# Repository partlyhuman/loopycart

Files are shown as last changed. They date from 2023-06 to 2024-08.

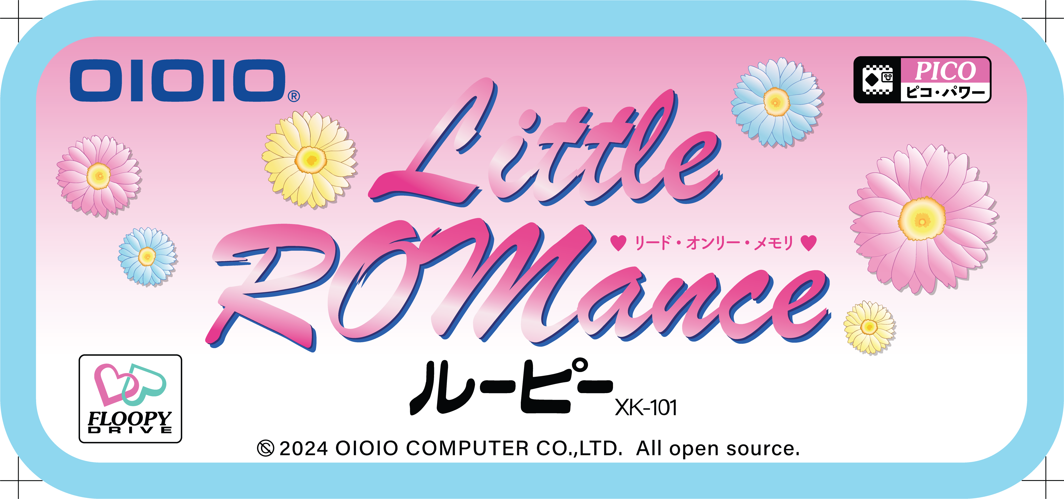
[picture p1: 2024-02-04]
labels/ROMance-1200dpi.png

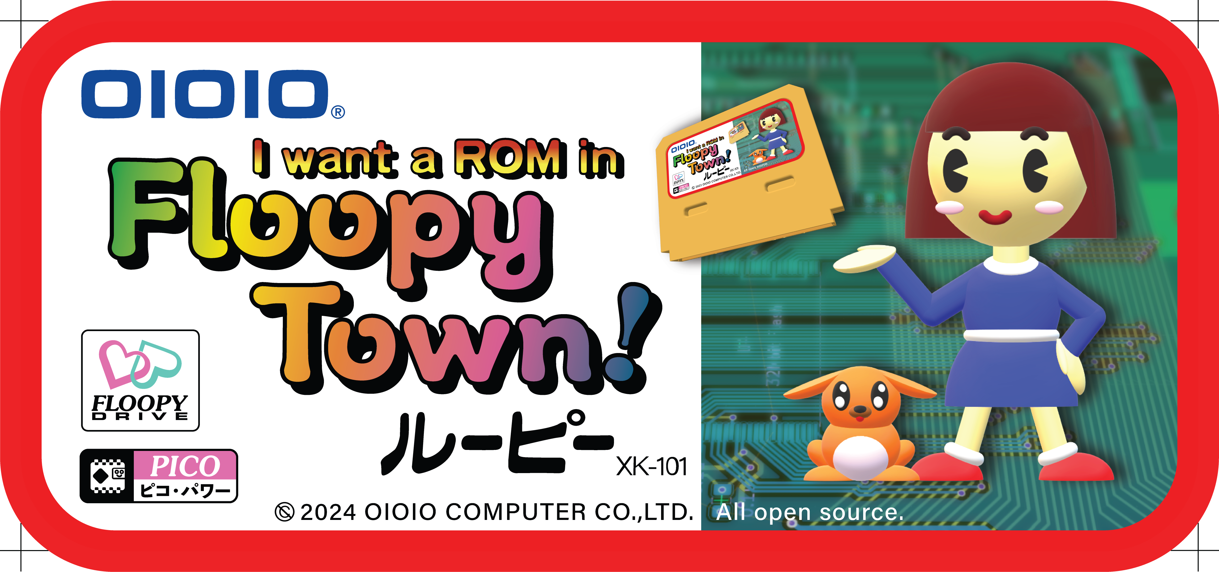
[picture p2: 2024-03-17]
labels/FloopyTown-1200dpi.png

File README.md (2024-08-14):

# the Floopy Drive 💕

This is a flashcart/devcart for the Casio Loopy. 

[☕️ Pre-built carts shipping worldwide on loopy.land/shop](https://loopy.land/shop)

[📖 User's Guide](https://github.com/partlyhuman/loopycart/wiki)

[YouTube<br>📺 Introductory Video](http://www.youtube.com/watch?v=_Q8cJwyDRfA)

To help find your way around:

* [pcb/flash-32mbit/](pcb/flash-32mbit/) The star of the show, the Floopy Drive PCB
* [flash-programmer/](flash-programmer/) Firmware that runs on the Floopy Drive, plus the PC interface for flashing it
* [cart-shell/](cart-shell/) 3D printable case for the Floopy Drive
* [labels/](labels/) Printable labels you can affix to a finished Floopy Drive
* [pcb/](pcb/) Other boards built along the way include a reverse-engineered cart that started it all
* [scans/](scans/) Scans of de-populated OEM Loopy games used as reference
* [data/](data/) Archive of relevant part datasheets for quick reference

Related repositories:

* [OSCR](https://github.com/sanni/cartreader) — I contributed a Casio Loopy adapter and code to the Open Source Cartridge Dumper, as well as a [makeshift adapter](https://github.com/sanni/cartreader/discussions/354#discussioncomment-10103848) that doesn't require an original cart connector
* [Loopy-Tools](https://github.com/kasamikona/Loopy-Tools) — a treasure trove of documentation and tooling around the Loopy by @kasamikona
* [Loopy-Schematics](https://github.com/kasamikona/Loopy-Schematics) - Schematics for various parts of, and accessories for, the Casio Loopy by @kasamikona
* [LoopyMSE](https://github.com/PSI-Rockin/LoopyMSE) — an open-source cross-platform Loopy emulator by @PSI-Rockin

### Contributors! 💕

None of this would be possible without the contributions of [@kasamikona](https://github.com/kasamikona) and [@kvanderlaag](https://github.com/kvanderlaag), with many, many additional thanks to the members of the [Unloved Budget Computer Hole](https://discord.gg/DH8cArK2) Discord server.

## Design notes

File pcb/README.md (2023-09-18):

# Loopy flashcarts/devcarts

* [flash-32mbit](flash-32mbit/) — the Floopy Drive, with 32Mbit tri-voltage flash, and 256kbit SRAM
* [cart-connector](cart-connector/) — cart connector, footprint and symbol, for use in dumpers etc.
* [reverse-singlerom](reverse-singlerom/) — this is the AN1M cart design that we first reverse engineered
* [reverse-wanwan](reverse-wanwan/) — expanding upon that to try to document wanwan, schematic only so far

Some earlier revisions and experiments are in git history.

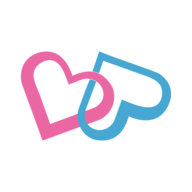
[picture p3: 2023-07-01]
flash-programmer/www/src/assets/android-chrome-192x192.png

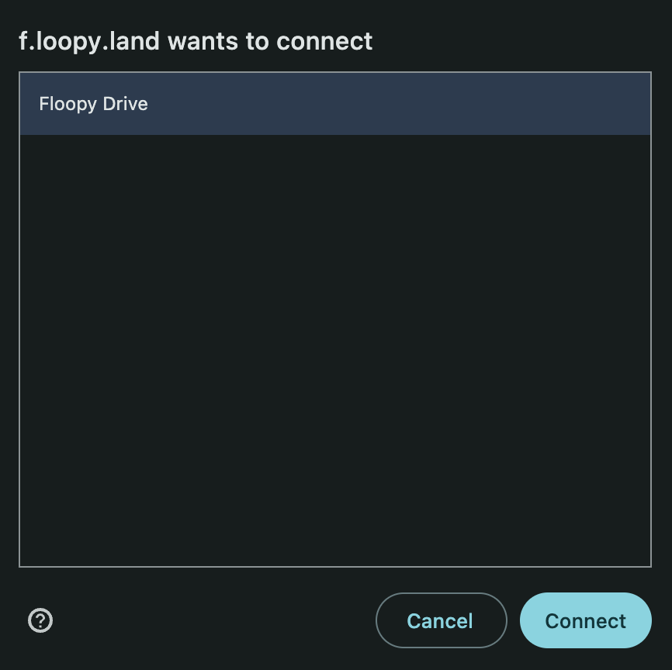
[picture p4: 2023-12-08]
docs/wants-to-connect.png

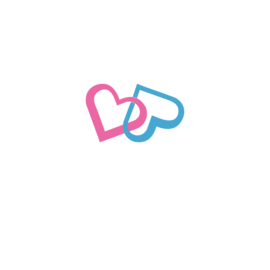
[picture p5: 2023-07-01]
flash-programmer/www/src/assets/mstile-150x150.png

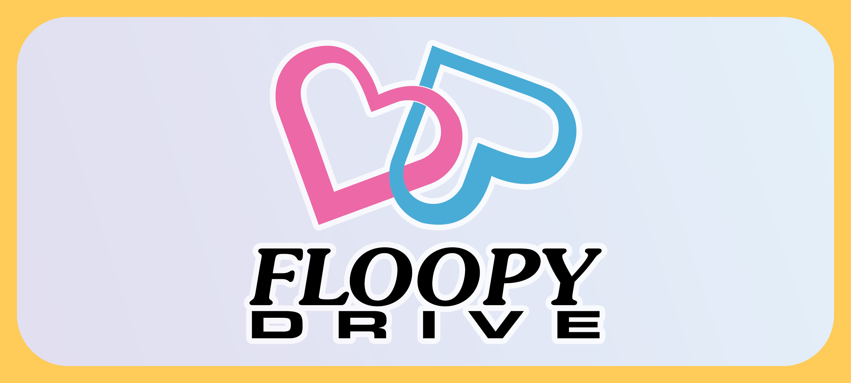
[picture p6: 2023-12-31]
labels/plain.png

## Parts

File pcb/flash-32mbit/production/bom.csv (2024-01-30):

Designator | Footprint | Quantity | Value | LCSC Part #
BT1 | Keystone-3034TR-MFG | 1 | CR2032
C1 | 0805 | 1 | 1u
C2, C4, C5, C6, C7 | 0805 | 5 | 0.1u
D1 | SOT-23 | 1 | BAT54C
D2 | SOT-23-3 | 1 | PMEG4005CT,215
D3 | SOT-23 | 1 | BSS138
J1 | LOOPY_Cart_Edge | 1 | ~
R1 | 0805 | 1 | 1K2
R10 | 0805 | 1 | 2K2
R11, R14, R3, R4, R5, R8 | 0805 | 6 | 100K
R12 | 0805 | 1 | 10K
R13, R2, R6, R9 | 0805 | 4 | 1K
U1 | TSOP-I-56_18.4x14mm_P0.5mm-HandSolder | 1 | LH28F320SKTD-L70
U2 | SOIC127P1410X300-32N | 1 | AS6C1008-55SIN
U3 | SOT-23-5 | 1 | SN74LVC1G04
U4 | RP2040-Tiny | 1 | RP2040-Tiny
U5, U6, U7 | SSOP-28_5.3x10.2mm_P0.65mm | 3 | MCP23S17T-E/SS

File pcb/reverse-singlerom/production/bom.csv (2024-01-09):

Designator | Footprint | Quantity | Value | LCSC Part #
IC11 | LOOPY-SOIC-44 | 1 | ~
J11, J12 | PinHeader_1x21_P2.54mm_Vertical | 2 | Conn_01x21_Pin

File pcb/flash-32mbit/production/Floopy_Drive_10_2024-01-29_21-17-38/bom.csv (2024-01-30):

Designator | Footprint | Quantity | Value | LCSC Part #
BT1 | Keystone-3034TR-MFG | 1 | CR2032
C1 | 0805 | 1 | 1u
C2, C4, C5, C6, C7 | 0805 | 5 | 0.1u
D1 | SOT-23 | 1 | BAT54C
D2 | SOT-23-3 | 1 | PMEG2005CT_215
D3 | SOT-23 | 1 | BSS138
J1 | LOOPY_Cart_Edge | 1 | ~
R1 | 0805 | 1 | 1K2
R10 | 0805 | 1 | 2K2
R11, R3, R4, R8 | 0805 | 4 | 100K
R12 | 0805 | 1 | 10K
R13, R2, R6, R9 | 0805 | 4 | 1K
R14, R5 | 0805 | 2 | 100K | DNP
U1 | TSOP-I-56_18.4x14mm_P0.5mm-HandSolder | 1 | LH28F320SKTD-L70
U2 | SOIC127P1410X300-32N | 1 | AS6C1008-55SIN
U3 | SOT-23-5 | 1 | SN74LVC1G04
U4 | RP2040-Tiny | 1 | RP2040-Tiny
U5, U6, U7 | SSOP-28_5.3x10.2mm_P0.65mm | 3 | MCP23S17T-E/SS

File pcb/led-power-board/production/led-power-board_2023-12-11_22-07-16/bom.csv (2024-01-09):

Designator | Footprint | Quantity | Value | LCSC Part #
D1 | LED_D5.0mm | 1 | LED
J1 | PinHeader_1x02_P2.54mm_Vertical | 1 | Conn_01x02_Pin
R1 | R_Axial_DIN0207_L6.3mm_D2.5mm_P10.16mm_Horizontal | 1 | 1K

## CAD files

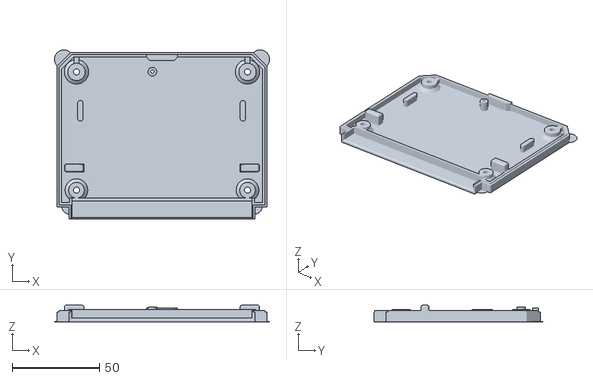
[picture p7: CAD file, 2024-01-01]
cart-shell/FloopyDrive-Rear-MouseEars.stl
123.4 x 97.1 x 9.60

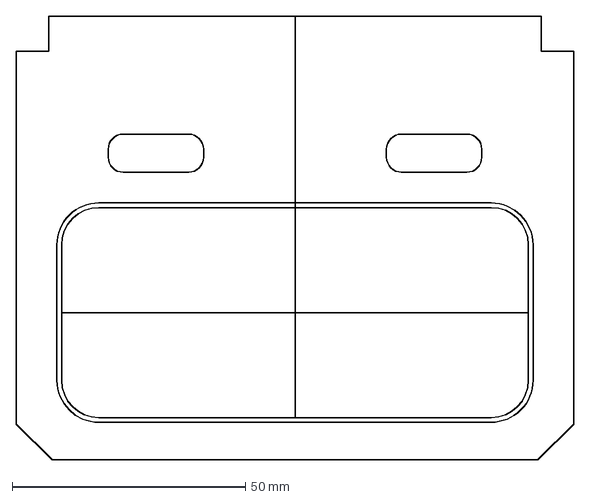
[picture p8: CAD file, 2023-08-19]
labels/floopycart-label.dxf
119.4 x 95.1 mm

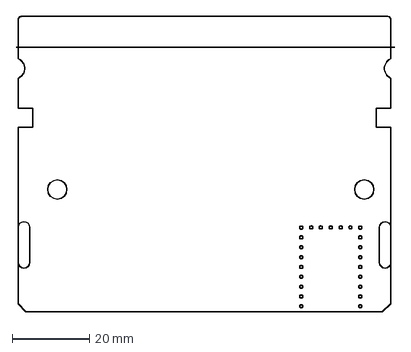
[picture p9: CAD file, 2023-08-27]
pcb/flash-32mbit/Reference/PCB Keepouts Front.dxf
97.8 x 76.3 mm

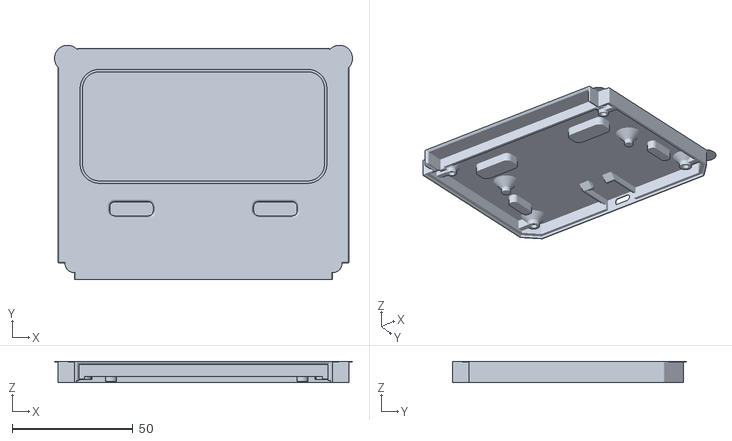
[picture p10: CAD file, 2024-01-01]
cart-shell/FloopyDrive-Front-MouseEars.stl
123.4 x 97.1 x 8.85

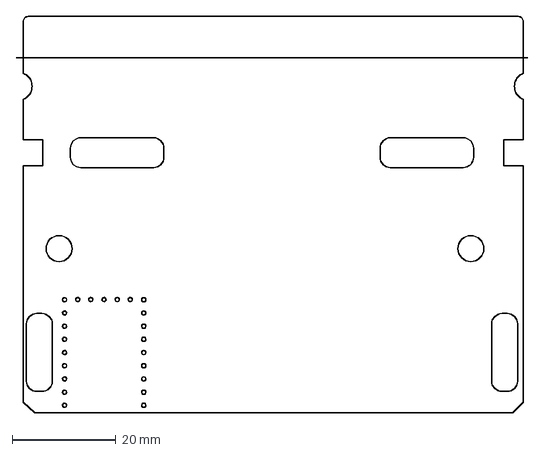
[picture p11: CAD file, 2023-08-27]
pcb/flash-32mbit/Reference/PCB Keepouts Rear.dxf
98.4 x 76.3 mm

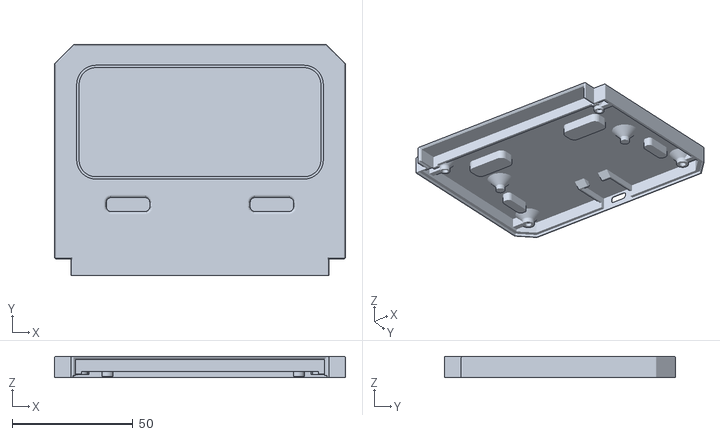
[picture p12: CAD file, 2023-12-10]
cart-shell/FloopyDrive-Front.stl
120.6 x 95.7 x 8.85

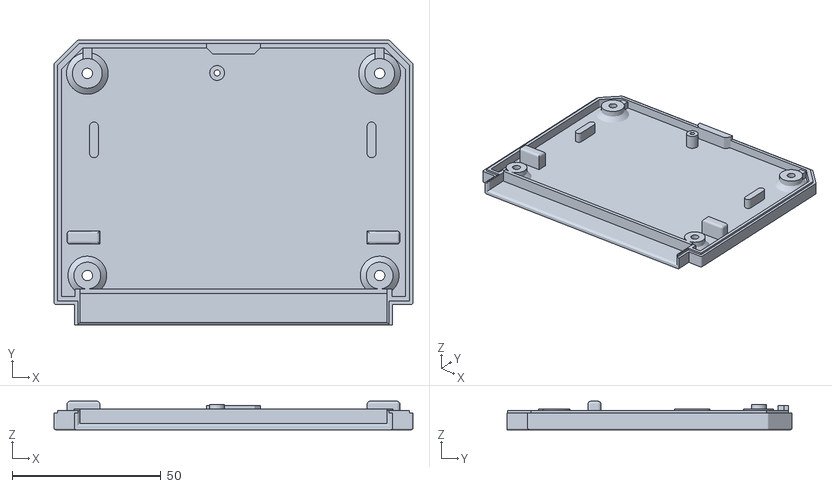
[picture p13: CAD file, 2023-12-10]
cart-shell/FloopyDrive-Rear.stl
120.6 x 95.7 x 9.60

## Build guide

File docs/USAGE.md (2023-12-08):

> NOTE migrated to https://github.com/partlyhuman/loopycart/wiki

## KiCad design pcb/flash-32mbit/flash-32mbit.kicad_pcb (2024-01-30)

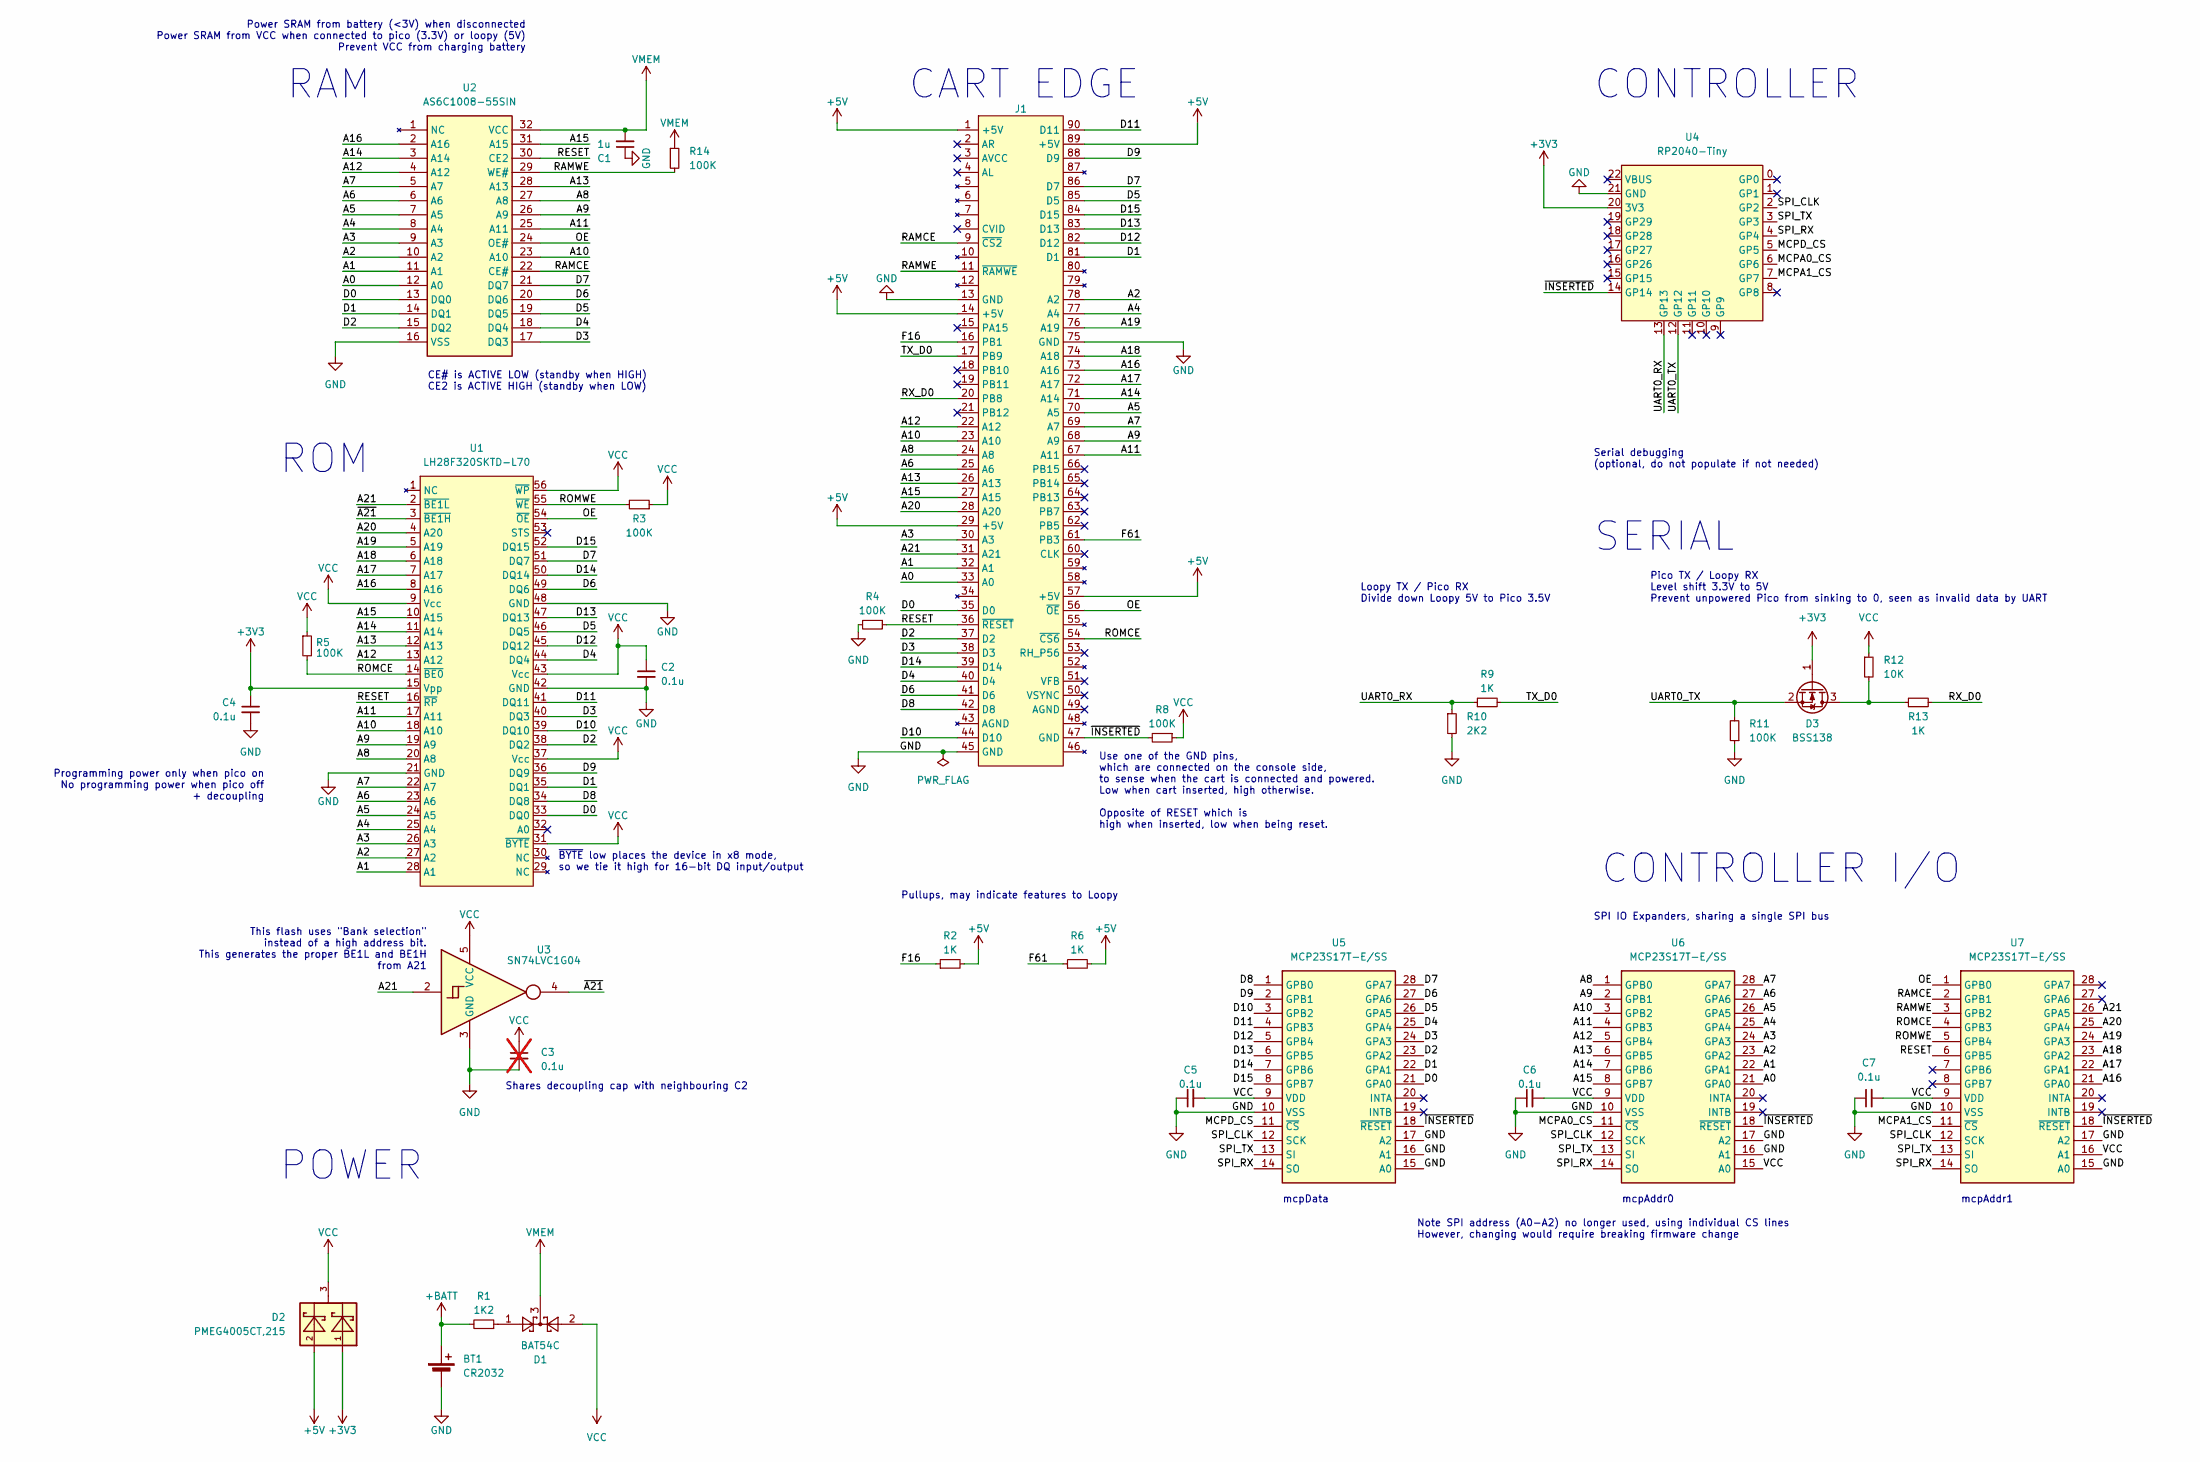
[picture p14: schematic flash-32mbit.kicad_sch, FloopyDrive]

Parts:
BT1: CR2032; Keystone-3034TR-MFG
C1: 1u; C_0805_2012Metric_Pad1.18x1.45mm_HandSolder
C2, C4, C5, C6, C7: 0.1u; C_0805_2012Metric_Pad1.18x1.45mm_HandSolder
C3: 0.1u; C_0805_2012Metric_Pad1.18x1.45mm_HandSolder; not fitted
D1: BAT54C; SOT-23
D2: PMEG4005CT,215; SOT-23-3
D3: BSS138; SOT-23
J1: LOOPY_Cart_Edge
R1: 1K2; R_0805_2012Metric_Pad1.20x1.40mm_HandSolder
R2, R6, R9, R13: 1K; R_0805_2012Metric_Pad1.20x1.40mm_HandSolder
R3, R4, R5, R8, R11, R14: 100K; R_0805_2012Metric_Pad1.20x1.40mm_HandSolder
R10: 2K2; R_0805_2012Metric_Pad1.20x1.40mm_HandSolder
R12: 10K; R_0805_2012Metric_Pad1.20x1.40mm_HandSolder
U1: LH28F320SKTD-L70; TSOP-I-56_18.4x14mm_P0.5mm-HandSolder
U2: AS6C1008-55SIN; SOIC127P1410X300-32N; Manufacturer_Part_Number AS6C1008-55SIN; Mouser Part Number 913-AS6C1008-55SIN
U3: SN74LVC1G04; SOT-23-5
U4: RP2040-Tiny
U5, U6, U7: MCP23S17T-E/SS; SSOP-28_5.3x10.2mm_P0.65mm; Manufacturer_Part_Number MCP23S17T-E/SO; Mouser Part Number 579-MCP23S17T-E/SO

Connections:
+3V3: C4.1, D2.1, D3.1 (G), U1.15 (Vpp), U4.20 (3V3)
+5V: D2.2, J1.1 (+5V), J1.14 (+5V), J1.29 (+5V), J1.57 (+5V), J1.89 (+5V), R2.2, R6.2
+BATT: BT1.1 (+), R1.2
/A0: J1.33 (A0), U2.12 (A0), U6.21 (GPA0)
/A1: J1.32 (A1), U1.28 (A1), U2.11 (A1), U6.22 (GPA1)
/A2: J1.78 (A2), U1.27 (A2), U2.10 (A2), U6.23 (GPA2)
/A3: J1.30 (A3), U1.26 (A3), U2.9 (A3), U6.24 (GPA3)
/A4: J1.77 (A4), U1.25 (A4), U2.8 (A4), U6.25 (GPA4)
/A5: J1.70 (A5), U1.24 (A5), U2.7 (A5), U6.26 (GPA5)
/A6: J1.25 (A6), U1.23 (A6), U2.6 (A6), U6.27 (GPA6)
/A7: J1.69 (A7), U1.22 (A7), U2.5 (A7), U6.28 (GPA7)
/A8: J1.24 (A8), U1.20 (A8), U2.27 (A8), U6.1 (GPB0)
/A9: J1.68 (A9), U1.19 (A9), U2.26 (A9), U6.2 (GPB1)
/A10: J1.23 (A10), U1.18 (A10), U2.23 (A10), U6.3 (GPB2)
/A11: J1.67 (A11), U1.17 (A11), U2.25 (A11), U6.4 (GPB3)
/A12: J1.22 (A12), U1.13 (A12), U2.4 (A12), U6.5 (GPB4)
/A13: J1.26 (A13), U1.12 (A13), U2.28 (A13), U6.6 (GPB5)
/A14: J1.71 (A14), U1.11 (A14), U2.3 (A14), U6.7 (GPB6)
/A15: J1.27 (A15), U1.10 (A15), U2.31 (A15), U6.8 (GPB7)
/A16: J1.73 (A16), U1.8 (A16), U2.2 (A16), U7.21 (GPA0)
/A17: J1.72 (A17), U1.7 (A17), U7.22 (GPA1)
/A18: J1.74 (A18), U1.6 (A18), U7.23 (GPA2)
/A19: J1.76 (A19), U1.5 (A19), U7.24 (GPA3)
/A20: J1.28 (A20), U1.4 (A20), U7.25 (GPA4)
/A21: J1.31 (A21), U1.2 (~BE1L), U3.2, U7.26 (GPA5)
/D0: J1.35 (D0), U1.33 (DQ0), U2.13 (DQ0), U5.21 (GPA0)
/D1: J1.81 (D1), U1.35 (DQ1), U2.14 (DQ1), U5.22 (GPA1)
/D2: J1.37 (D2), U1.38 (DQ2), U2.15 (DQ2), U5.23 (GPA2)
/D3: J1.38 (D3), U1.40 (DQ3), U2.17 (DQ3), U5.24 (GPA3)
/D4: J1.40 (D4), U1.44 (DQ4), U2.18 (DQ4), U5.25 (GPA4)
/D5: J1.85 (D5), U1.46 (DQ5), U2.19 (DQ5), U5.26 (GPA5)
/D6: J1.41 (D6), U1.49 (DQ6), U2.20 (DQ6), U5.27 (GPA6)
/D7: J1.86 (D7), U1.51 (DQ7), U2.21 (DQ7), U5.28 (GPA7)
/D8: J1.42 (D8), U1.34 (DQ8), U5.1 (GPB0)
/D9: J1.88 (D9), U1.36 (DQ9), U5.2 (GPB1)
/D10: J1.44 (D10), U1.39 (DQ10), U5.3 (GPB2)
/D11: J1.90 (D11), U1.41 (DQ11), U5.4 (GPB3)
/D12: J1.82 (D12), U1.45 (DQ12), U5.5 (GPB4)
/D13: J1.83 (D13), U1.47 (DQ13), U5.6 (GPB5)
/D14: J1.39 (D14), U1.50 (DQ14), U5.7 (GPB6)
/D15: J1.84 (D15), U1.52 (DQ15), U5.8 (GPB7)
/F16: J1.16 (PB1), R2.1
/F61: J1.61 (PB3), R6.1
/MCPA0_CS: U4.6 (GP6), U6.11 (~CS)
/MCPA1_CS: U4.7 (GP7), U7.11 (~CS)
/MCPD_CS: U4.5 (GP5), U5.11 (~CS)
/OE: J1.56 (~OE), U1.54 (~OE), U2.24 (OE#), U7.1 (GPB0)
/RAMCE: J1.9 (~CS2), U2.22 (CE#), U7.2 (GPB1)
/RAMWE: J1.11 (~RAMWE), R14.2, U2.29 (WE#), U7.3 (GPB2)
/RESET: J1.36 (~RESET), R4.1, U1.16 (~RP), U2.30 (CE2), U7.6 (GPB5)
/ROMCE: J1.54 (~CS6), R5.2, U1.14 (~BE0), U7.4 (GPB3)
/ROMWE: R3.2, U1.55 (~WE), U7.5 (GPB4)
/RX_D0: J1.20 (PB8), R13.2
/SPI_CLK: U4.2 (GP2), U5.12 (SCK), U6.12 (SCK), U7.12 (SCK)
/SPI_RX: U4.4 (GP4), U5.14 (SO), U6.14 (SO), U7.14 (SO)
/SPI_TX: U4.3 (GP3), U5.13 (SI), U6.13 (SI), U7.13 (SI)
/TX_D0: J1.17 (PB9), R9.2
/UART0_RX: R9.1, R10.1, U4.13 (GP13)
/UART0_TX: D3.2 (S), R11.2, U4.12 (GP12)
/~A21: U1.3 (~BE1H), U3.4
/~INSERTED: J1.47 (GND), R8.2, U4.14 (GP14), U5.18 (~RESET), U6.18 (~RESET), U7.18 (~RESET)
GND: BT1.2 (-), C1.1, C2.2, C3.2, C4.2, C5.1, C6.1, C7.1, J1.13 (GND), J1.45 (GND), J1.75 (GND), R4.2, R10.2, R11.1, U1.21 (GND), U1.42 (GND), U1.48 (GND), U2.16 (VSS), U3.3 (GND), U4.21 (GND), U5.10 (VSS), U5.15 (A0), U5.16 (A1), U5.17 (A2), U6.10 (VSS), U6.16 (A1), U6.17 (A2), U7.10 (VSS), U7.15 (A0), U7.17 (A2)
unnamed: D1.1, R1.1
unnamed: D3.3 (D), R12.2, R13.1
VCC: C2.1, C3.1, C5.2, C6.2, C7.2, D1.2, D2.3, R3.1, R5.1, R8.1, R12.1, U1.9 (Vcc), U1.31 (~BYTE), U1.37 (Vcc), U1.43 (Vcc), U1.56 (~WP), U3.5 (VCC), U5.9 (VDD), U6.9 (VDD), U6.15 (A0), U7.9 (VDD), U7.16 (A1)
VMEM: C1.2, D1.3, R14.1, U2.32 (VCC)

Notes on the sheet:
Use one of the GND pins, which are connected on the console side, to sense when the cart is connected and powered. Low when cart inserted, high otherwise. Opposite of RESET which is high when inserted, low when being reset.
Power SRAM from battery (<3V) when disconnected Power SRAM from VCC when connected to pico (3.3V) or loopy (5V) Prevent VCC from charging battery
POWER
RAM
Shares decoupling cap with neighbouring C2
ROM
Loopy TX / Pico RX Divide down Loopy 5V to Pico 3.5V
CE# is ACTIVE LOW (standby when HIGH) CE2 is ACTIVE HIGH (standby when LOW)
Note SPI address (A0-A2) no longer used, using individual CS lines However, changing would require breaking firmware change
CART EDGE
mcpAddr0
mcpAddr1
This flash uses "Bank selection" instead of a high address bit. This generates the proper BE1L and BE1H from A21
Programming power only when pico on No programming power when pico off + decoupling
Pullups, may indicate features to Loopy
Serial debugging (optional, do not populate if not needed)
Pico TX / Loopy RX Level shift 3.3V to 5V Prevent unpowered Pico from sinking to 0, seen as invalid data by UART
SERIAL
SPI IO Expanders, sharing a single SPI bus
~{BYTE} low places the device in x8 mode, so we tie it high for 16-bit DQ input/output
CONTROLLER
CONTROLLER I/O
mcpData

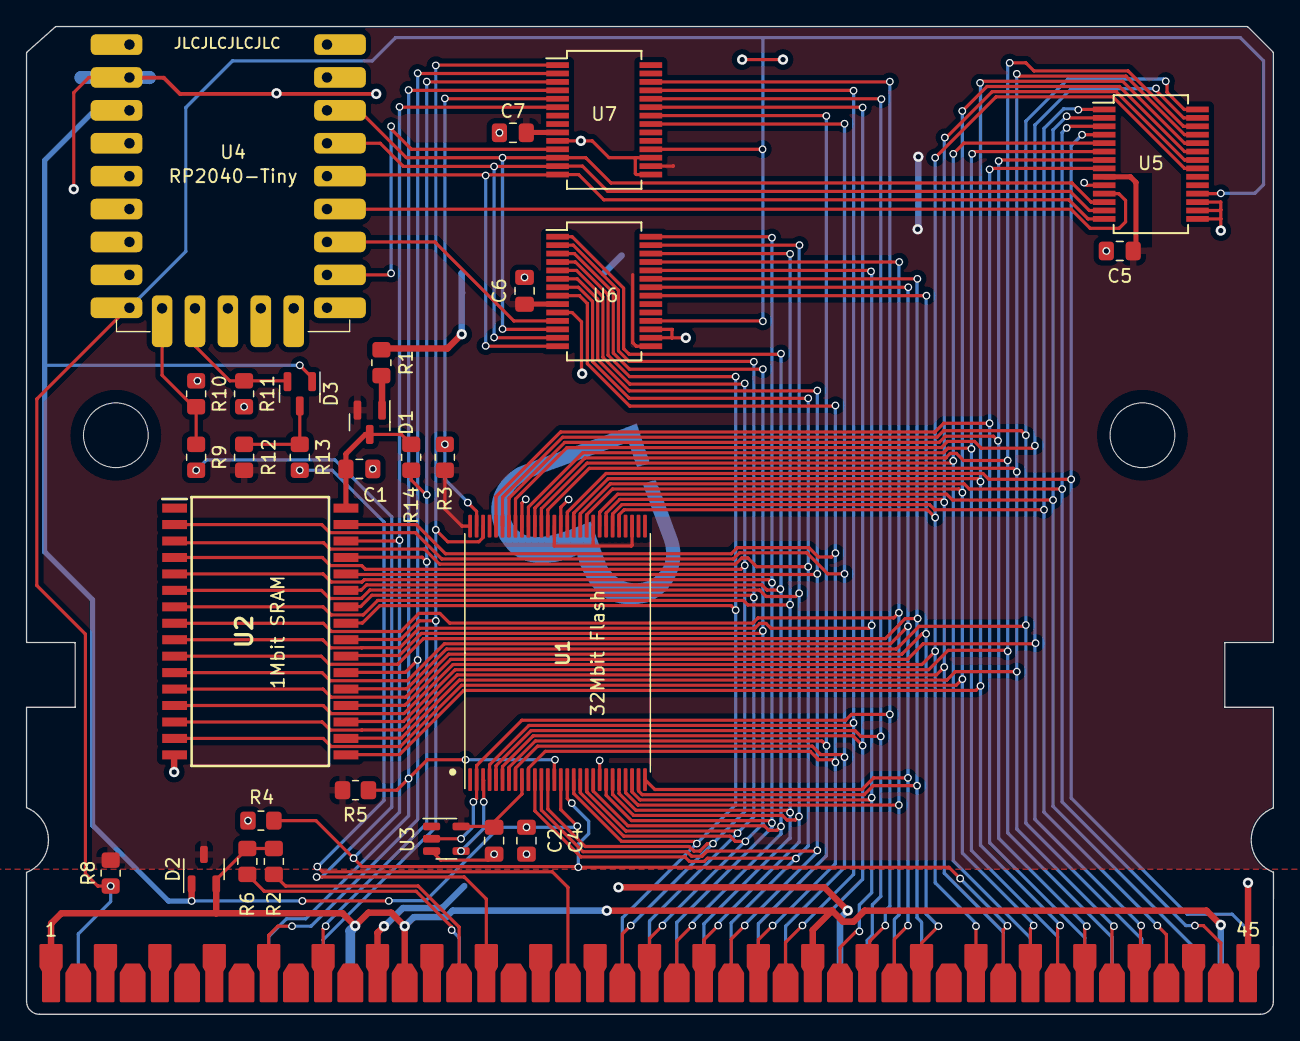
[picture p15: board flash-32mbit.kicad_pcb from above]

Board: 2 copper layers, 96.3 x 76.2 mm, 33 parts (1 on the bottom side), 66 nets.

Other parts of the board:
H1, H2: MountingHole_5mm

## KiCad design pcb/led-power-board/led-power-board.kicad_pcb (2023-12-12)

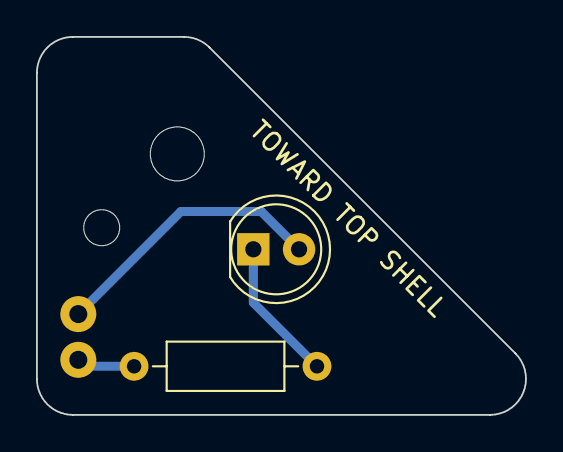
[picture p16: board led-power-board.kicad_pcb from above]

Board: 2 copper layers, 27.2 x 21.0 mm, 6 parts (1 on the bottom side), 3 nets.

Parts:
D1: LED; LED_D5.0mm
J1: Conn_01x02_Pin; PinHeader_1x02_P2.54mm_Vertical
M1: MountingHole_3mm
M2, M3: MountingHole_2mm
R1: 1K; R_Axial_DIN0207_L6.3mm_D2.5mm_P10.16mm_Horizontal

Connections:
unnamed: D1.2 (A), J1.1
unnamed: D1.1 (K), R1.2
unnamed: J1.2, R1.1

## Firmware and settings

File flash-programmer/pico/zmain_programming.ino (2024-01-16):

#define ABORT_AFTER_MS 1000

// Keep Adafruit VID, custom PID for programming
#define VID_PROG 0x239A
#define PID_PROG 0xF100

static int bootErrors = 0;

void onSuccess(bool echoOk = true) {
  if (echoOk) echo_ok();
  busIdle();
  ledColor(0);
}

void loop_programming() {
  static uint8_t buf[USB_BUFSIZE];
  static bool isProgrammingFlash = false;
  static bool isProgrammingSram = false;
  static uint32_t addr = 0;
  static uint32_t totalBytes;
  static uint32_t idleSince = 0;


  if (!usb_web.available()) {
    // DEBUGGING idle detect shows the pico is still looping if other things have halted due to error
    if (idleSince == 0) {
      idleSince = millis();
    } else if (millis() - idleSince > ABORT_AFTER_MS) {
      if (isProgrammingFlash || isProgrammingSram) {
        isProgrammingFlash = false;
        isProgrammingSram = false;
        echo_all("!ERROR Aborted programming after no data\r\n");
      }
    }
    return;
  }
  idleSince = 0;

  size_t bufLen = usb_web.read(buf, USB_BUFSIZE);

  if (isProgrammingFlash) {
    isProgrammingFlash = flashWriteBuffer(buf, bufLen, addr, totalBytes);
    if (!isProgrammingFlash) onSuccess();
    return;
  } else if (isProgrammingSram) {
    isProgrammingSram = sramWriteBuffer(buf, bufLen, addr, totalBytes);
    if (!isProgrammingSram) onSuccess();
    return;
  }

  else if (buf[0] == 'E') {
    // ERASE COMMAND
    if (buf[1] == '\r') {
      ledColor(BLUE);
      flashEraseAll();
      flashCommand(0, CMD_RESET);
      onSuccess();
    } else if (buf[1] == 's' && buf[2] == '\r') {
      ledColor(BLUE);
      sramErase();
      onSuccess();
    } else if (buf[1] == '0' && buf[2] == '\r') {
      // DEPRECATED
      ledColor(BLUE);
      flashEraseBank(0);
      flashCommand(0, CMD_RESET);
      onSuccess();
    } else if (buf[1] == '1' && buf[2] == '\r') {
      // DEPRECATED
      ledColor(BLUE);
      flashEraseBank(1);
      flashCommand(0, CMD_RESET);
      onSuccess();
    } else if (sscanf((char *)buf, "E%ld\r", &totalBytes) && totalBytes > 0 && totalBytes <= FLASH_SIZE) {
      stopwatch = millis();
      sprintf(S, "Erasing %d bytes of flash up to %06xh\r\n", totalBytes, totalBytes);
      echo_all();
      ledColor(BLUE);
      for (addr = 0; addr < totalBytes; addr += FLASH_BLOCK_SIZE) {
        sprintf(S, "%06xh ", addr);
        echo_all();
        if (!flashEraseBlock(addr)) {
          echo_all("\r\n!ERR ABORTING ERASE\r\n");
          return;
        }
      }
      // // NOTE: Erasing by bank isn't faster than erasing by block, so this adds complexity but saves no time
      // addr = 0;
      // while (addr < totalBytes) {
      //   sprintf(S, "%06xh ", addr);
      //   echo_all();
      //   if (addr == 0 && totalBytes >= FLASH_BANK_SIZE) {
      //     flashEraseBank(0);
      //     addr += FLASH_BANK_SIZE;
      //   } else if (addr == FLASH_BANK_SIZE && totalBytes == FLASH_BANK_SIZE * 2) {
      //     flashEraseBank(1);
      //     addr += FLASH_BANK_SIZE;
      //   } else {
      //     if (!flashEraseBlock(addr)) {
      //       echo_all("\r\n!ERR ABORTING ERASE\r\n");
      //       return;
      //     }
      //   }
      // }
      sprintf(S, "\r\nErased %d bytes in %0.2f sec using block erasing\r\n", addr, (millis() - stopwatch) / 1000.0);
      echo_all();
      onSuccess();
    }
  }

  else if (buf[0] == 'I' && buf[1] == '\r') {
    // INSPECT COMMAND
    // flashId();
    echo_all("\r\n---CART-ID---\r\n");
    sprintf(S, "Cart header %s\r\n", flashCartHeaderCheck() ? "OK" : "NOT OK");
    echo_all();
    sprintf(S, "Cart ID %08x\r\n", flashCartHeaderId());
    echo_all();
    echo_all("\r\n---FLASH-lower---\r\n");
    flashInspect(0x000000, 0x000100);
    echo_all("\r\n------\r\n");
    flashInspect(0x100000, 0x100100);
    echo_all("\r\n---FLASH-upper---\r\n");
    flashInspect(0x200000, FLASH_BANK_SIZE + 0x000100);
    echo_all("\r\n------\r\n");
    flashInspect(0x300000, FLASH_BANK_SIZE + 0x100100);
    echo_all("\r\n---SRAM---\r\n");
    sramInspect(0, 0x100);
    echo_all("\r\n---FILESYSTEM---\r\n");
    Dir dir = LittleFS.openDir("/");
    while (dir.next()) {
      echo_all(dir.fileName().c_str());
      echo_all("\r\n");
    }

    // Some info in the info64 struct comes out as zeroes
    // FSInfo64 info;
    // LittleFS.info64(info);
    FSInfo info;
    LittleFS.info(info);
    sprintf(S, "%d/%d bytes used, %0.0f%% full\r\n", info.usedBytes, info.totalBytes, 100.0 * (info.usedBytes + 0.0) / info.totalBytes);
    echo_all();
    onSuccess();
  }

  else if (buf[0] == 'D') {
    // DUMP COMMAND
    if (2 == sscanf((char *)buf, "D%ld/%ld\r", &addr, &totalBytes)) {
      // followed by start address and total # of bytes
      if (addr > 0 && totalBytes > 0 && totalBytes <= FLASH_SIZE) {
        ledColor(BLUE);
        flashDump(addr, addr + totalBytes);
        onSuccess(false);
      } else {
        ledColor(RED);
      }
    } else if (1 == sscanf((char *)buf, "D%ld\r", &totalBytes)) {
      // followed by expected # of bytes
      if (totalBytes > 0 && totalBytes <= FLASH_SIZE) {
        ledColor(BLUE);
        flashDump(0, totalBytes);
        onSuccess(false);
      } else {
        ledColor(RED);
      }
    } else if (buf[1] == 's' && buf[2] == '\r') {
      sramDump();
      onSuccess(false);
    }
  }

  else if (buf[0] == 'P') {
    // PROGRAM COMMAND
    if (1 == sscanf((char *)buf, "P%ld\r", &totalBytes) && totalBytes > 0 && totalBytes <= FLASH_SIZE) {
      // program flash followed by expected # of bytes
      sprintf(S, "Programming %d bytes to flash\r", totalBytes);
      echo_all();
      isProgrammingFlash = true;
      addr = 0;
      stopwatch = millis();
      ledColor(BLUE);
    } else if (1 == sscanf((char *)buf, "Ps%ld\r", &totalBytes) && totalBytes > 0 && totalBytes <= SRAM_SIZE) {
      // program SRAM followed by expected # of bytes
      sprintf(S, "Programming %d bytes to SRAM\r", totalBytes);
      echo_all();
      isProgrammingSram = true;
      addr = 0;
      stopwatch = millis();
      ledColor(BLUE);
    }
  }

  else if (buf[0] == 'S') {
    // SRAM BACKUP & RESTORE FROM FILESYSTEM

    // ID the header
    uint32_t cartId = flashCartHeaderId();

    // we always use <crc32>.sav which is 8 1 3 = 12 chars plus string terminator = 13 bytes
    const size_t SAVE_FILENAME_LEN = 13;
    char filename[SAVE_FILENAME_LEN];
    sprintf(filename, "%08x.sav", cartId);

    if (buf[1] == 'r' && buf[2] == '\r') {
      // backup SRAM to file
      uint32_t sramSize = min(flashCartHeaderSramSize(), SRAM_SIZE);
      sprintf(S, "Backing up first %d bytes of SRAM to %s\r\n", sramSize, filename);
      echo_all();
      ledColor(BLUE);
      sramSaveFile(filename, sramSize);
      onSuccess();
    } else if (buf[1] == 'w' && buf[2] == '\r') {
      // restore SRAM from file
      sprintf(S, "Restoring SRAM contents from %s\r\n", filename);
      echo_all();
      uint32_t sramSize = min(flashCartHeaderSramSize(), SRAM_SIZE);
      ledColor(BLUE);
      sramLoadFile(filename) || sramErase(sramSize);
      onSuccess();
    } else if (buf[1] == 'f' && buf[2] == '\r') {
      // Clear filesystem!
      echo_all("Clearing all save states stored on Floopy Drive!!\r\n");
      ledColor(BLUE);
      LittleFS.format();
      onSuccess();
    }
  }

  else if (buf[0] == 'N') {
    if (sscanf((char *)buf, "N%[^\r]\r", S) && strlen(S) > 0) {
      setNickname(S);
      onSuccess();
    } else {
      setNickname(NULL);
      onSuccess();
    }
  }

  else if (buf[0] != '\r') {
    // Received unknown command OR it's possible we returned to idle state before the sender was done sending?
    echo_all("Unrecognized command\r\n");
    ledColor(0xce4e04);  // orange
  }
}

void onUsbConnect(bool connected) {
  if (connected) {
    char connectStr[USB_BUFSIZE];
    for (int i = 0; i < USB_BUFSIZE; i++) {
      connectStr[i] = '\r';  // make printable
    }
    // Spit out firmware and hardware revisions first thing on connect
    // Ensure we append existing string buffer S which contains any preexisting boot logging
    sprintf(connectStr, "!FW %s\r\n!HW %d\r\n", GIT_COMMIT, HW_REVISION);
    usb_web.write((uint8_t *)connectStr, USB_BUFSIZE);
    usb_web.flush();

    if (bootErrors > 0) {
      echo_all();
      echo_all("\r\n!ERR boot log errors found above\r\n");
    }
  }
}

inline void bootError(const char *str, uint32_t ledErrorColor = 0x800000) {
  bootErrors++;
  sprintf(S, "%s %s", S, str);
  ledColor(ledErrorColor);
}

void setup_programming() {
  // Serial allows us to more easily reset/reprogram the Pico
  // In production, consider reworking echo_all and removing this?
  Serial.begin(115200);

  // Filesystem. Auto formats. Make sure to reserve size in Tools > Flash Size
  // If we wanted to customize the block size could use something like this modifying 4096, perhaps down to 1024
  // FS LittleFS = FS(FSImplPtr(new littlefs_impl::LittleFSImpl(&_FS_start, &_FS_end - &_FS_start, 256, 4096, 16)));
  if (!LittleFS.begin()) bootError("littleFS fail");

  // USB setup
  TinyUSBDevice.setID(VID_PROG, PID_PROG);
  // Reads nickname from FS, must place after LittleFS.begin
  const char *deviceName = makeNicknamedDeviceName();
  TinyUSBDevice.setProductDescriptor(deviceName);
  usb_web.setLandingPage(&landingPage);
  usb_web.setLineStateCallback(onUsbConnect);
  usb_web.setStringDescriptor(deviceName);
  usb_web.begin();

  // Setup IO expanders
  SPI.begin();
  mcpAddr0.setSPIClockSpeed(SPI_SPEED);
  mcpAddr1.setSPIClockSpeed(SPI_SPEED);
  mcpData.setSPIClockSpeed(SPI_SPEED);
  if (!mcpAddr0.Init()) bootError("mcpAddr0 fail");
  if (!mcpAddr1.Init()) bootError("mcpAddr1 fail");
  if (!mcpData.Init()) bootError("mcpData fail");

  ioWriteMode(&mcpData);
  ioWriteMode(&mcpAddr0);

  // CAREFUL what happens when some of these active-low control lines are set momentarily
  busIdle();
  ioWriteMode(&mcpAddr1);
  busIdle();

  // DON'T Backup SRAM contents whenever Pico is booted up - this would ruin things when changing batteries
  // if (!bootErrors && flashCartHeaderCheck()) {
  //   uint32_t cartId = flashCartHeaderId();
  //   if (cartId != 0 && cartId != 0xffffffff) {
  //     ledColor(BLUE);
  //     const size_t SAVE_FILENAME_LEN = 13;
  //     char filename[SAVE_FILENAME_LEN];
  //     sprintf(filename, "%08x.sav", cartId);
  //     sramSaveFile(filename, min(flashCartHeaderSramSize(), SRAM_SIZE));
  //     ledColor(0);
  //   }
  // }

  // Clear flash lock bits preemptively whenever Pico is booted up
  if (!bootErrors) {
    flashClearLocks();
  }

  // Let either claim the USB
  while (!TinyUSBDevice.mounted() && !Serial) {
    delay(1);
  }

  if (!bootErrors) {
    // Give a little flash to indicate boot and connection ok, otherwise leave error status LED unchanged
    ledColor(0xff0000);
    delay(50);
    ledColor(0x00ff00);
    delay(50);
    ledColor(0x0000ff);
    delay(50);
    ledColor(0);
  }
}

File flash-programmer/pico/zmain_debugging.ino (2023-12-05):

// Keep Adafruit VID, custom PID for debugging (different from programming)
#define PID_DEBUG 0x239A
#define VID_DEBUG 0xF10D

int debugBaud = 38400;

void loop_debugging() {
  // Check for changed baud rate
  // Better to do this with callbacks if possible?
  int requestedBaud = Serial.baud();
  if(requestedBaud != debugBaud) {
    debugBaud = requestedBaud;
    Serial1.end(); // Maybe flush is enough?
    Serial1.begin(debugBaud);
  }

  // USB -> Loopy
  if (Serial.available()) {
    uint8_t b = Serial.read();
    Serial1.write(b);
  }

  // Loopy -> USB
  if (Serial1.available()) {
    uint8_t b = Serial1.read();
    Serial.write(b);
  }
}

void setup_debugging() {
  ledColor(0x001000);

  // Serial; // USB serial
  TinyUSBDevice.setID(VID_DEBUG, PID_DEBUG);
  //TinyUSBDevice.setProductDescriptor("Floopy Drive (Debug)"); // Adafruit_USBD_CDC annoyingly overrides this, fix with custom class?
  Serial.begin(debugBaud);

  // Serial1; // UART0 on alternative pins
  Serial1.setRX(13);
  Serial1.setTX(12);
  Serial1.setFIFOSize(256);
  Serial1.setPollingMode(true);
  Serial1.begin(debugBaud);

  // Wait for USB connection
  while (!Serial) {
    delay(1);
  }

  ledColor(0x008000);
}

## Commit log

2023-03-04 Add link to Google Sheet
    [Casio Loopy ICs (Cartridges and Systems) - Carts.csv]
2023-03-05 start reversing single rom cart
    [reverse-singlerom.kicad_sch]
2023-03-05 reversing some pins
    [reverse-singlerom.kicad_sch]
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2023-03-05 Traced all signal routes
    [reverse-singlerom.kicad_sch]
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2023-03-06 Adds power to reverse engineered cart
    [reverse-singlerom.kicad_sch]
2023-03-06 Adds feature detect pins, fixes DRC errors
    [reverse-singlerom.kicad_sch]
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2023-03-08 Annotates cart edge symbol
    [reverse-singlerom.kicad_sch]
2023-03-08 Update notes, pass ERC, pass DRC
    [reverse-singlerom.kicad_sch]
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2023-03-21 Adds devcart rev 0
    [singlerom-dev.kicad_pcb, singlerom-dev.kicad_sch]
2023-04-10 Adds Pi Pico header + IO expander for on-board programming, starting over with manual routing
    [singlerom-dev.kicad_pcb, singlerom-dev.kicad_sch]
2023-04-11 Add header pin breakout for SOP44 maskrom
    [maskrom_breakout.kicad_sch, reverse-singlerom.kicad_sch]
2023-04-11 Work on rerouting devcart
    [singlerom-dev.kicad_pcb]
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2023-04-16 Correcting wrong flash IC, footprint, symbol. Still needs rerouting but removed incorrect one.
    [singlerom-dev.kicad_pcb, singlerom-dev.kicad_sch]
2023-04-16 Fix schematic with 16mbit
    [singlerom-dev.kicad_sch]
2023-04-16 Schematic update better matching sram mapping
    [reverse-singlerom.kicad_sch, singlerom-dev.kicad_sch]
2023-04-17 Forget FRAM for now, redesign around pin compatible SRAM, nuke old routes
    [singlerom-dev.kicad_pcb, singlerom-dev.kicad_sch]
2023-04-19 Replicate power path controller for SRAM from original
    [singlerom-dev.kicad_pcb, singlerom-dev.kicad_sch]
2023-04-19 Nudging clearances
    [singlerom-dev.kicad_pcb, singlerom-dev.kicad_sch]
2023-04-19 Match pin numbers on battery so + faces up
    [singlerom-dev.kicad_pcb, singlerom-dev.kicad_sch]
2023-04-30 WIP some fixes, not completed but didn't want to leave broken
    [singlerom-dev.kicad_pcb, singlerom-dev.kicad_sch]
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2023-05-10 Quick patching BYTE issue
    [singlerom-dev.kicad_pcb]
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2023-05-16 WIP reverse engineering wanwan cart's extra circuitry
    [maskrom_breakout.kicad_sch, reverse-wanwan.kicad_sch]
2023-05-16 Updating more pins on wanwan
    [reverse-wanwan.kicad_sch]
2023-05-16 WIP on wanwan schematic, all cart edge pins identified
    [reverse-wanwan.kicad_sch]
2023-05-16 Adds datasheets for chips found on wanwan
    [Casio Loopy ICs (Cartridges and Systems) - Carts.csv]
2023-05-16 Revise pin descriptions for oki sound chip
    [reverse-wanwan.kicad_sch]
2023-05-17 Convert Pico to castellated footprint and reroute; add logo
    [singlerom-dev.kicad_pcb, singlerom-dev.kicad_sch]
2023-05-21 Very experimental changes in separate directory
    [singlerom-4Mtest-kasami.kicad_pcb, singlerom-4Mtest-kasami.kicad_sch]
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2023-05-22 Added BAT54C to Pico 3V3 line; coin cell moved to rear; forehead removed
    [singlerom-dev.kicad_pcb, singlerom-dev.kicad_sch]
2023-05-23 Removing test jumpers and points
    [singlerom-dev.kicad_pcb, singlerom-dev.kicad_sch]
2023-05-28 32mbit and 3.3v updates to schematic
    [singlerom-dev.kicad_pcb]
2023-05-29 vreg and resistor packs
    [singlerom-dev.kicad_sch]
2023-05-29 Copy project to new directory
    [flash-32mbit.kicad_pcb, flash-32mbit.kicad_sch]
2023-05-29 Restore original from git
    [singlerom-dev.kicad_pcb, singlerom-dev.kicad_sch]
2023-05-29 Switch Flash part to Sharp LH28F320SKTD-L70
    [flash-32mbit.kicad_pcb, flash-32mbit.kicad_sch]
2023-05-29 Preliminary routing
    This sucks, so feel free to reroute literally anything or move stuff around
    [flash-32mbit.kicad_pcb]
2023-05-29 More garbage routing; removed resistor packs
    [flash-32mbit.kicad_pcb, flash-32mbit.kicad_sch]
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2023-05-30 Update IO expander 3D model
    [flash-32mbit.kicad_pcb]
2023-05-30 Add 10K pulldown to flash Vpp, decoupling cap
    [flash-32mbit.kicad_pcb, flash-32mbit.kicad_sch]
2023-05-30 Adds datasheet, decouples IO exp
    [flash-32mbit.kicad_pcb, flash-32mbit.kicad_sch]
2023-06-05 Minor fix idk
    [singlerom-4Mtest-kasami.kicad_pcb]
2023-06-09 I2C speedup, fix erase status, fix slowdown on FFFF blocks
    [pico.ino]
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2023-06-14 Adds cart connector footprint
    [cart-connector.kicad_pcb, cart-connector.kicad_sch]
2023-06-16 Minor cart edge footprint changes
    [cart-connector.kicad_pcb]
2023-06-23 First stab at rev.3 firmware
    [flash-32mbit.kicad_sch]
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2023-06-24 Change physical stackup to show board thickness of 1mm
    [flash-32mbit.kicad_pcb]
2023-06-25 Correct value for io expanders, mcp2317 is not the same as mcp2318
    [flash-32mbit.kicad_sch]
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2023-06-28 Fixes multibyte programming upper bank
    [flash.ino, sram.ino, zmain.ino]
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2023-06-28 Beef up screw holes on rear cart shell
    [FloopyDrive-Rear.stl]
2023-06-28 Corrects power select diode in schematic
    [flash-32mbit.kicad_pcb, flash-32mbit.kicad_sch]
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2023-07-16 Fixes to sram processes
    [sram.ino]
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2023-07-16 Adds 256kb SRAM to schematic, some reorganizing of libraries
    [flash-32mbit.kicad_sch]
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2023-07-22 Flash routed but the orientation is misleading, savepoint...
    [flash-32mbit.kicad_pcb]
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2023-07-23 Pullup RAMCE since new SRAM only has one chip select pin
    [flash-32mbit.kicad_pcb, flash-32mbit.kicad_sch]
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2023-08-13 Update to use @kasamikona's edge connector (renumbered to match)
    [flash-32mbit.kicad_pcb, flash-32mbit.kicad_sch]
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2023-08-13 Minor fix to RP2040-Tiny footprint
    [flash-32mbit.kicad_pcb]
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2023-08-24 Fixes dumping bug on firmware, improves web interface with progress, routines to dump and parse header, dumping correct size based on dumped header
    [flash.ino, pico.ino]
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2023-08-27 Moves components out of keepout areas, RESET no longer connected
    [flash-32mbit.kicad_pcb, flash-32mbit.kicad_sch]
2023-08-27 Gives each expander its own CS line (help bus interference?)
    [flash-32mbit.kicad_pcb, flash-32mbit.kicad_sch]
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2023-08-27 Updates shell with wider space for ribbon found on another seller's Pico Tiny, and updated pcb model
    [FloopyDrive-Front-NoLabel.stl, FloopyDrive-Front.stl, FloopyDrive-Rear.stl]
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2023-08-29 Reverts powering pico from loopy
    [flash-32mbit.kicad_pcb]
2023-09-11 Fixes SRAM low power mode on schematic, needs routing
    [flash-32mbit.kicad_sch]
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2023-09-24 Fixes sram getting byte 0 set to 0; SRAM programmer improvements
    [flash.ino, pico.ino, sram.ino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]
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2023-09-28 Tidying, using RESET to power down flash, marking potentially redundant pullups
    [flash-32mbit.kicad_pcb, flash-32mbit.kicad_sch]
2023-09-28 Now that asserting RESET low keeps some things safe, let pico drive RESET high only when ready
    [flash-32mbit.kicad_pcb, flash-32mbit.kicad_sch]
2023-09-28 /RESET pulled low, power up and down conditions should be covered by this and extra control pullups should be redundant
    [flash-32mbit.kicad_pcb, flash-32mbit.kicad_sch]
2023-10-22 Fixes voltage divider resistor order
    [flash-32mbit.kicad_pcb, flash-32mbit.kicad_sch]
2023-10-22 Revert "Fixes voltage divider resistor order"
    This reverts commit 804d36860d2d035c957d0a79ec73a7ea4df5a67d.
    [flash-32mbit.kicad_pcb, flash-32mbit.kicad_sch]
2023-10-22 Corrects serial RX and fixes issue with unpowered serial TX
    [flash-32mbit.kicad_sch]
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2023-10-23 Consolidating blocker diodes and using higher current PMEG2005CT
    [flash-32mbit.kicad_pcb, flash-32mbit.kicad_sch]
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2023-11-25 Corrects vendor ID on USB device filter
    [zmain_programming.ino]
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2023-12-07 VERY WIP rgb flex cable
    [rgb-mod.kicad_pcb, rgb-mod.kicad_sch]
2023-12-09 Rev9 minor change that moves F16/F61 pullups far away from edge connector
    [flash-32mbit.kicad_pcb, flash-32mbit.kicad_sch]
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2023-12-12 Replacement LED power board with place for resistor
    [led-power-board.kicad_pcb, led-power-board.kicad_sch]
2023-12-28 Fixes to make send/receives always a single 'packet' size, adding QA functionality, builds to come
    [flash.ino, pico.ino]
2023-12-28 Fixes broken nickname method, minor cleanups
    [zmain_programming.ino]
2024-01-01 Adds stls with mouse ears for better adhesion
    [FloopyDrive-Front-MouseEars.stl, FloopyDrive-Rear-MouseEars.stl]
2024-01-01 Ugh, lots of fixes, support for QA, new build follows
    [flash.ino, pico.ino, sram.ino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]
2024-01-09 Unignore CSV to allow bom etc to be added
    [bom.csv, designators.csv, positions.csv]
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2024-01-15 Firmware bugfixes: stalls on finishing some flash writes, only erasing needed amount of SRAM, possible misinterpretation of header when sram still selected
    [flash.ino, sram.ino, zmain_programming.ino]
2024-01-16 Cleaning up fw around where control lines are set - pushing down into low level functions, relieving the need to correctly set up state in every higher level function. Fixes clear screen bug.
    [flash.ino, sram.ino, zmain_programming.ino]
2024-01-30 Rev 10 - changing MCP23S17 from SOP28 to SSOP28
    [bom.csv, designators.csv, flash-32mbit.kicad_pcb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]
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2024-01-30 Flips backwards text on rear silk
    [flash-32mbit.kicad_pcb]
2024-01-30 Revert "Flips backwards text on rear silk"
    This reverts commit 23c83f32a1717887e789bbf7f9e156f244039a19.
    [flash-32mbit.kicad_pcb]
2024-01-30 Revert "Converting RP2040 to SMD-only pads"
    This reverts commit 3f45febaba06878acc33683eaa9a11db4d2374d0.
    [bom.csv, designators.csv, flash-32mbit.kicad_pcb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]
2024-01-30 Disallows direct connection between pads, updates schematic to reflect new PMEG part and restoring the DNP components we have been using
    [bom.csv, designators.csv, flash-32mbit.kicad_pcb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]
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2024-06-09 Remove aborted wanwan reversing, see https://github.com/kasamikona/Loopy-Schematics
    [maskrom_breakout.kicad_sch, reverse-wanwan.kicad_sch]
